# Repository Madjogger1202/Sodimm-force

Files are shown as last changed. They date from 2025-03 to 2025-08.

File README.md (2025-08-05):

# Sodimm-force rev0 
> [!IMPORTANT]
> Project wasn't produced and tested yet.
### Implementation of Orange Pi Zero 2W in sodimm form-factor
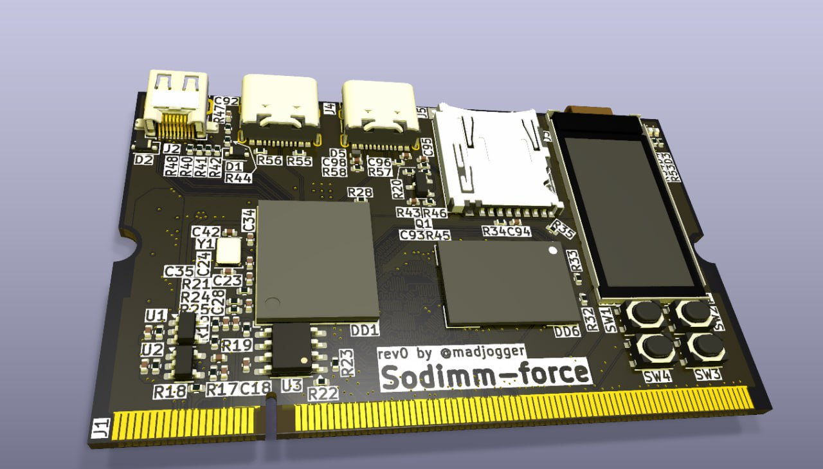
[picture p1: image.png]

<table style="width: 100%; table-layout: fixed;">
  <tr>
    <td rowspan="4">
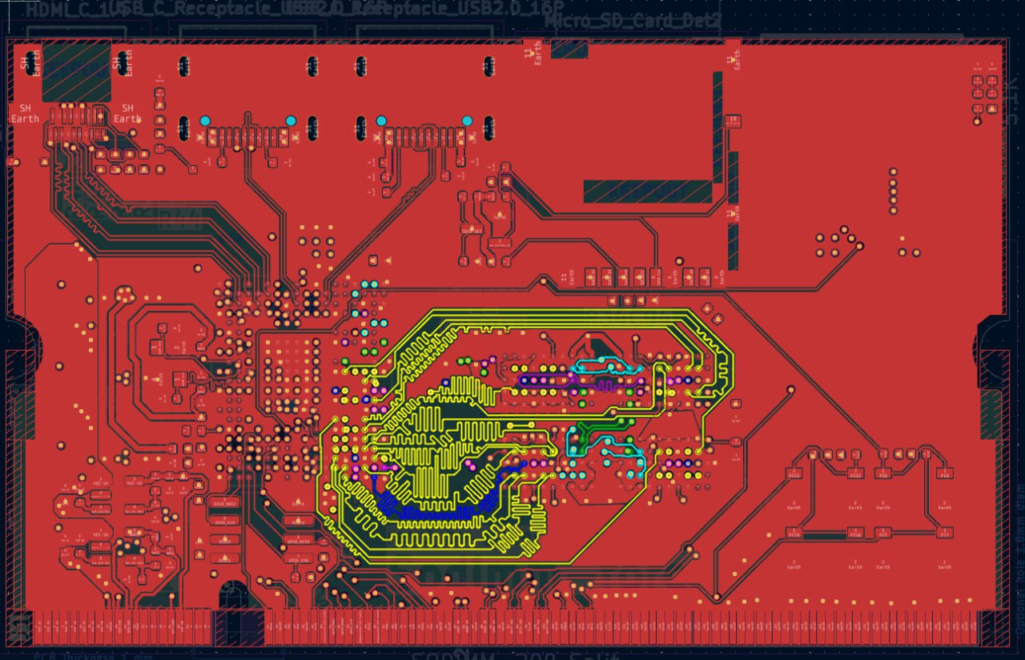
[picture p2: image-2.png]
      
    </td>  
    <td rowspan="4">
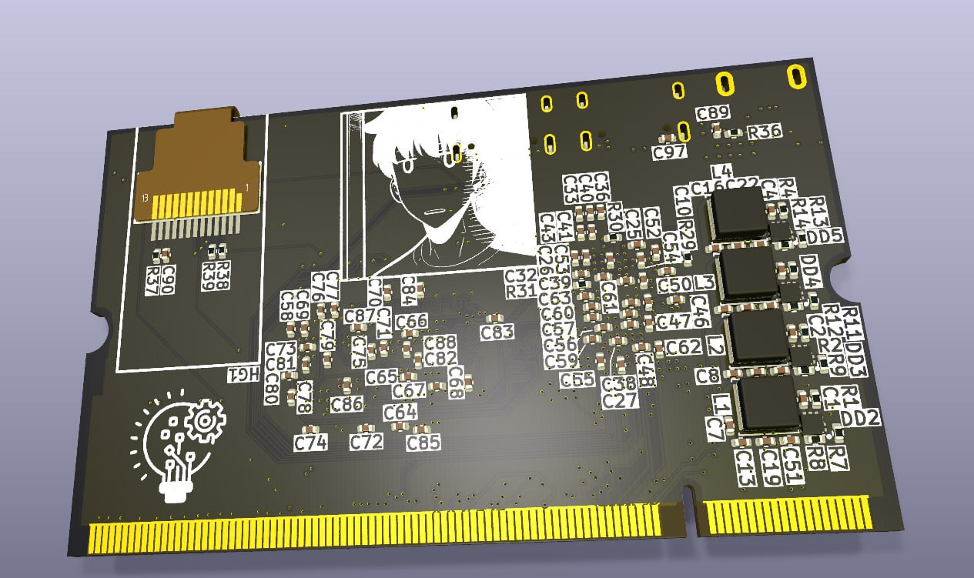
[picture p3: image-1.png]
      
    </td>  
  </tr>
</table>

## 🎲Revisions and logs:
<table>
  <tr>
    <td>
      <strong>Revision 0</strong>
    </td>   
    <td>
      <strong>10 March 2025</strong>
    </td> 
    <td>
      CPU H616, DDR MT53E1G32D2FW-046
    </td>
    <td>
      <strong>[x] not produced</strong>
    </td>
  </tr>
</table>

## 🧊 What Is This Project?

🐾 This entire project is just my take on an embedded compute module — but built around the Allwinner H616 SoC.

Not a clone. Not a dev board.  
Just **a compact, modular, SODIMM-sized brain** for custom systems. 💡

---

### 🛠️ The Vision

🐈 Made it to explore:
- How far can you push a **low-cost ARM SoC** in real embedded applications?
- Can we build something **industrial-grade**, yet **hackable and open**?
- What if your compute unit was **as easy to swap as RAM**?

So I said: *"Let’s make a tiny computer on a SODIMM."*  
And here we are. ✨

---

### 🔌 Key Features (SODIMM Form Factor)

- 🧩 **Modular by design** — plug into any carrier board
- 🧠 **Allwinner H616** — Quad-core Cortex-A53, Mali-G31 GPU, 4K@60 decoding
- 💾 **4GB LPDDR4** (Micron, automotive-grade) — fast & stable
- 💾 **microSD slot** — boot OS, store logs, update firmware
- 🖤 **EEPROM (ST M24M02)** — stores calibration, MAC, serials
- 📺 **0.96" IPS display (ST7735)** — built-in UI, no external screen needed
- 🔘 **4 tactile buttons** — navigate menus, trigger actions
- 🔌 **microHDMI 2.0** — 4K video out
- 🔌 **2× USB Type-C** — data, OTG, power
- ⚡ **DC-DC + LDO power** (SY8843QWC + SPX3819) — clean, efficient, stable
- 🛡️ **ESD protection** on all critical lines — because real world is harsh

---

### 🎯 Why H616?

🌟 Not the most powerful.  
🌟 Not the newest.  

But:
- ✅ **Mature Linux support** (Armbian, Debian, Buildroot)
- ✅ **Low power & heat** — perfect for fanless, compact designs
- ✅ **Full HDMI 2.0 + USB OTG** — rare at this price
- ✅ **Industrial temp RAM** — works where others fail
- ✅ **Open-ish ecosystem** — community-driven, no NDA hell

---

### 🧪 This Is a Prototype — Not Production

- 🚧 **Revision 0** — proof of concept
- ❌ `[x] not produced` — still not produced

## **˙✧˖°📷 ༘ ⋆｡˚ Stay tuned for further updates.˙✧˖°📷 ༘ ⋆｡˚**

### ***For any questions or collaborations i can be found on Telegram: [@madjogger](https://t.me/madjogger)***

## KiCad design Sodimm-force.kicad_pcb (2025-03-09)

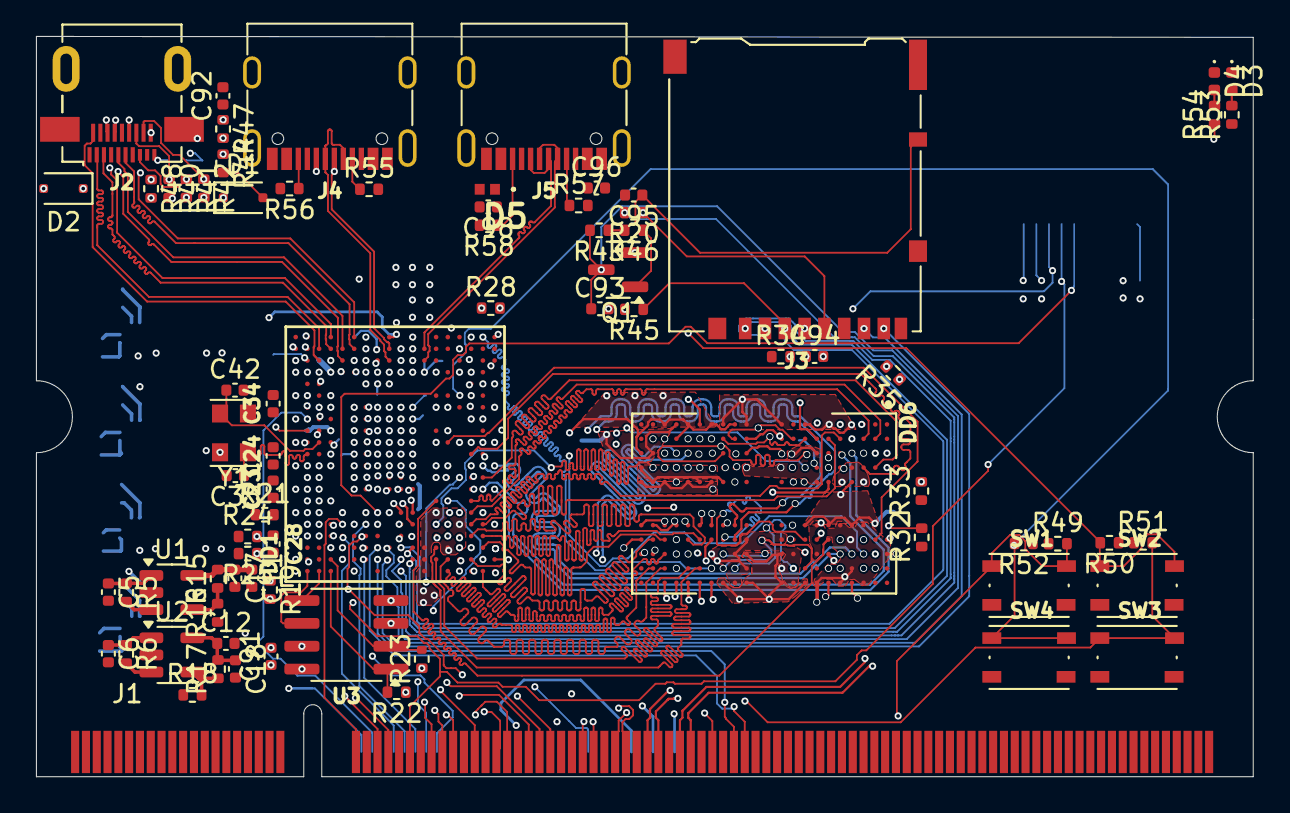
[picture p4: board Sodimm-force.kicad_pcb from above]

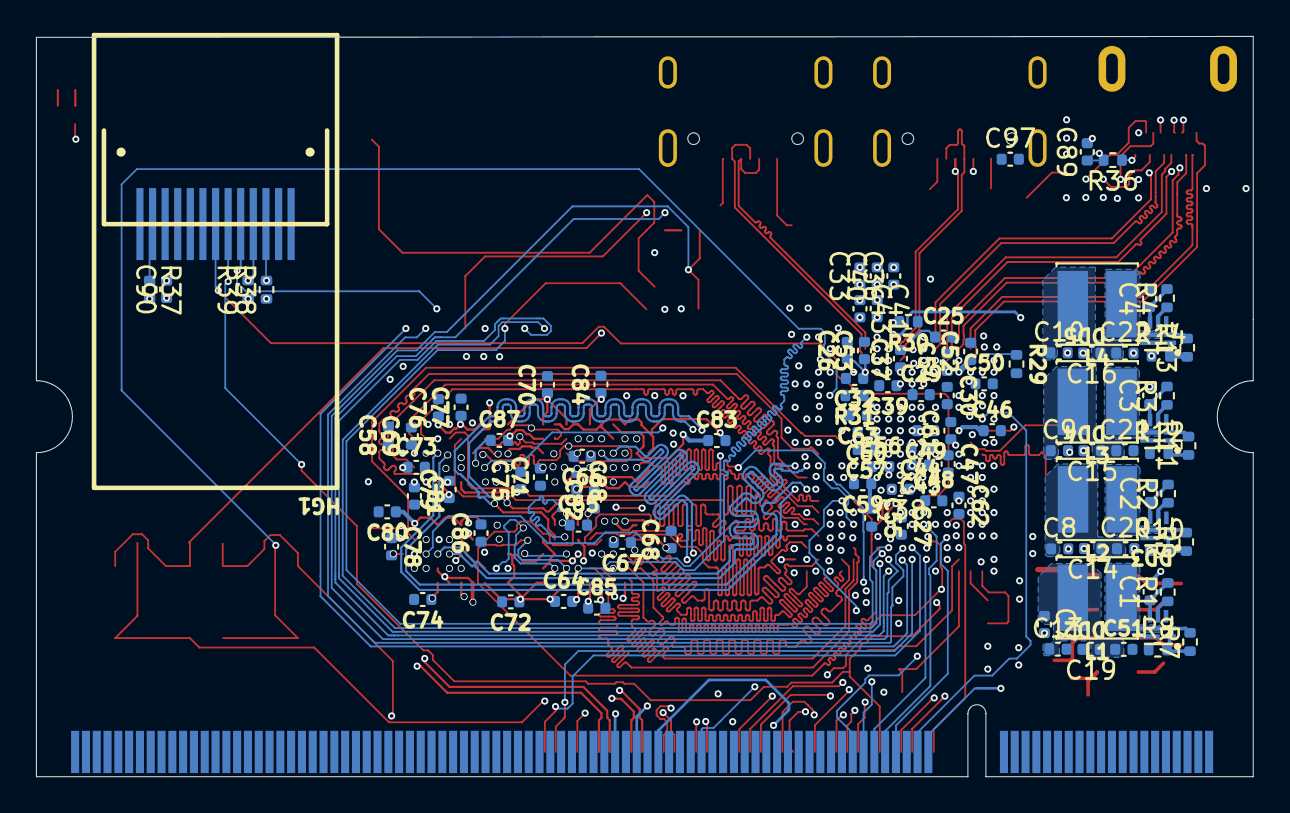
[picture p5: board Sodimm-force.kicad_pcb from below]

Board: 8 copper layers, 67.6 x 41.1 mm, 183 parts (106 on the bottom side), 182 nets.

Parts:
C1, C2, C3, C4, C5, C6, C7, C8, C9, C10, C11, C12, C19, C20, C21, C22, C33, C38, C41, C44, C47, C49, C53, C55, C64, C84, C90: 22uF; C_0402_1005Metric
C13, C14, C15, C16, C17, C18, C23, C24, C26, C28, C32, C61, C70, C71, C72, C73, C77, C78, C79, C80, C86, C88, C89, C92, C93, C95, C98: 100nF; C_0402_1005Metric
C25, C29, C52, C94, C96, C97: 10uF; C_0402_1005Metric
C27, C30, C34, C36, C40, C43, C45, C48, C51, C54, C56, C58, C60, C62, C65, C66, C67: 2.2uF; C_0402_1005Metric
C35, C42: 12p; C_0402_1005Metric
C37, C39, C46: 220nF; C_0402_1005Metric
C50, C57, C59, C63, C68, C69, C74, C75, C76, C81, C82, C83, C85, C87, C91: 1uF; C_0402_1005Metric
D1, D2: B5819WS; D_SOD-323F
D3, D4: LED-R; LED_0402_1005Metric
D5: AZ5825-01F; AZ582501F
DD1: H616
DD2, DD3, DD4, DD5: SY8843QWC
DD6: MT53E1G32D2FW-046_AUT_B; BGA200C65X80P22X12_1500X1000X114N
HG1: ST7735 0.96
J1: SODIMM-200_Split; SODIMM-200_2.5V_Card_edge
J2: HDMI_C_1.4; HDMI_Micro-D_Molex_46765-2x0x
J3: Micro_SD_Card_Det2; microSD_HC_Hirose_DM3AT-SF-PEJM5
J4, J5: USB_C_Receptacle_USB2.0_16P; USB_C_Receptacle_G-Switch_GT-USB-7010ASV
L1, L2, L3, L4: 0.68uH; L_Cenker_CKCS4020
Q1: 2N7002; SOT-23
R1, R2, R3, R4, R8, R10, R12, R22, R23, R24, R25, R38, R39, R49, R50, R51, R52: 10K; R_0402_1005Metric
R5, R6, R19: 0R; R_0402_1005Metric
R7: 5.1К; R_0402_1005Metric
R9: 6.8К; R_0402_1005Metric
R11: 8.32К; R_0402_1005Metric
R13: 41К; R_0402_1005Metric
R14: 9.1K; R_0402_1005Metric
R15: 16.9К; R_0402_1005Metric
R16: 10К; R_0402_1005Metric
R17: 4.7К; R_0402_1005Metric
R18: 10.2К; R_0402_1005Metric
R20, R21: 10R; R_0402_1005Metric
R28: 150K; R_0402_1005Metric
R29: 6K04; R_0402_1005Metric
R30, R31: 20K; R_0402_1005Metric
R32, R33: 240R; R_0402_1005Metric
R34, R35, R43, R45, R46: 100K; R_0402_1005Metric
R36: 1K; R_0402_1005Metric
R37, R40, R41, R42: 100R; R_0402_1005Metric
R44, R47, R48: 1.8K; R_0402_1005Metric
R53, R54, R57, R58: 5.1K; R_0402_1005Metric
R55, R56: 36K; R_0402_1005Metric
SW1, SW2, SW3, SW4: SW_Push; SW_Push_1P1T_NO_Vertical_Wuerth_434133025816
U1, U2: SPX3819M5-L; SOT-23-5
U3: SPI-EEPROM; SOIC-8_3.9x4.9mm_P1.27mm
Y1: X322524MKB4SI; Oscillator_SMD_EuroQuartz_XO32-4Pin_3.2x2.5mm

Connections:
AC-AVCC: C52.1, DD1.D18 (AC_AVCC)
AC-VRA1: C50.1, DD1.C17 (AC_VRA1)
AVCC: C12.1, C18.1, C23.1, C24.1, C25.1, C29.1, C34.1, C61.1, C62.1, C63.1, C84.1, C85.1, C86.1, C87.1, C88.1, DD1.D7 (VCC_PG), DD1.D11 (VCC_DCXO), DD1.D12 (VCC_PLL), DD1.F18 (VCC_HDMI), DD1.H17 (AVCC), DD1.H20 (VCC_TV), DD1.L14 (VDD18_DRAM), DD6.F12 (VDD1__1), DD6.G4 (VDD1__2), DD6.G9 (VDD1__3), DD6.T4 (VDD1__4), DD6.T9 (VDD1__5), DD6.U1 (VDD1__6), DD6.U12 (VDD1__7), J1.23, R17.2, R30.1, U2.5 (OUT)
DCDCE: C10.1, C16.1, C22.1, C90.1, C91.1, C94.1, DD5.2 (OUT), HG1.10 (VCC), J1.17, J3.4 (VDD), L4.2, R13.2, R22.1, R23.1, R24.1, R37.2, R38.1, R39.1, R43.1, R45.2, R46.2, R49.1, R50.1, R51.1, R52.1, R53.1, U3.3 (~W), U3.7 (~HOLD), U3.8 (VCC)
DCXO-XIN: C35.1, DD1.B11 (DXIN), Y1.1
DCXO-XOUT: C42.1, DD1.C12 (DXOUT), Y1.3
DXLDO-OUT: C46.1, DD1.D13 (DXLDO_OUT)
EPHY-RTX: DD1.B19 (EPHY_RTX), R29.1
EPHY-RXN: DD1.B21 (EPHY_RXN), J1.95
EPHY-RXP: DD1.B20 (EPHY_RXP), J1.97
EPHY-TXN: DD1.A20 (EPHY_TXN), J1.101
EPHY-TXP: DD1.A19 (EPHY_TXP), J1.103
Earth: C1.2, C2.2, C3.2, C4.2, C5.2, C6.2, C7.2, C8.2, C9.2, C10.2, C11.2, C12.2, C13.2, C14.2, C15.2, C16.2, C17.2, C18.2, C19.2, C20.2, C21.2, C22.2, C23.2, C24.2, C25.2, C26.2, C27.2, C28.2, C29.2, C30.2, C32.2, C33.2, C34.2, C35.2, C36.2, C37.2, C38.2, C39.2, C40.2, C41.2, C42.2, C43.2, C44.2, C45.2, C46.2, C47.2, C48.2, C49.2, C50.2, C51.2, C52.2, C53.2, C54.2, C55.2, C56.2, C57.2, C58.2, C59.2, C60.2, C61.2, C62.2, C63.2, C64.2, C65.2, C66.2, C67.2, C68.2, C69.2, C70.2, C71.2, C72.2, C73.2, C74.2, C75.2, C76.2, C77.2, C78.2, C79.2, C80.2, C81.2, C82.2, C83.2, C84.2, C85.2, C86.2, C87.2, C88.2, C89.2, C90.2, C91.2, C92.2, C93.2, C94.2, C95.2, C96.2, C97.2, C98.2, D3.1 (K), D4.1 (K), D5.2, DD1.A1 (GND_1), DD1.A10 (GND_2), DD1.A18 (GND_3), DD1.A21 (GND_4), DD1.B6 (GND_5), DD1.B16 (GND_6), DD1.D19 (GND_7), DD1.F14 (GND_8), DD1.F15 (GND_9), DD1.G13 (GND_10), DD1.G14 (GND_11), DD1.G15 (GND_12), DD1.H10 (GND_13), DD1.H11 (GND_14), DD1.H12 (GND_15), DD1.H13 (GND_16), DD1.H14 (GND_17), DD1.H15 (GND_18), DD1.H19 (GND_19), DD1.J12 (GND_20), DD1.J13 (GND_21), DD1.J14 (GND_22), DD1.J15 (GND_23), DD1.K8 (GND_24), DD1.K9 (GND_25), DD1.K10 (GND_26), DD1.K11 (GND_27), DD1.K12 (GND_28), DD1.K13 (GND_29), DD1.K14 (GND_30), DD1.K15 (GND_31), DD1.L21 (GND_32), DD1.M1 (GND_33), DD1.M2 (GND_34), DD1.M3 (GND_35), DD1.N6 (GND_36), DD1.N9 (GND_37), DD1.N12 (GND_38), DD1.N15 (GND_39), DD1.N18 (GND_40), DD1.P3 (GND_41), DD1.R5 (GND_42), DD1.R21 (GND_43), DD1.T1 (GND_44), DD1.T3 (GND_45), DD1.T8 (GND_46), DD1.T10 (GND_47), DD1.T15 (GND_48), DD1.T17 (GND_49), DD1.U6 (GND_50), DD1.U13 (GND_51), DD1.V1 (GND_52), DD1.V5 (GND_53), DD1.V12 (GND_54), DD1.V19 (GND_55), DD1.V21 (GND_56), DD2.7 (GND), DD3.7 (GND), DD4.7 (GND), DD5.7 (GND), DD6.A3 (VSS_1), DD6.A10 (VSS_1__1), DD6.AB3 (VSS_4), DD6.AB5 (VSS_4__1), DD6.AB8 (VSS_4__2), DD6.AB10 (VSS_4__3), DD6.C1 (VSS_1__2), DD6.C5 (VSS_1__3), DD6.C8 (VSS_1__4), DD6.C12 (VSS_1__5), DD6.D2 (VSS_1__6), DD6.D4 (VSS_1__7), DD6.D9 (VSS_1__8), DD6.D11 (VSS_1__9), DD6.E1 (VSS_1__10), DD6.E5 (VSS_1__11), DD6.E8 (VSS_1__12), DD6.E12 (VSS_1__13), DD6.G1 (VSS_1__14), DD6.G3 (VSS_2), DD6.G5 (VSS_2__1), DD6.G8 (VSS_2__2), DD6.G10 (VSS_2__3), DD6.G12 (VSS_2__4), DD6.J1 (VSS_2__5), DD6.J3 (VSS_2__6), DD6.J10 (VSS_2__7), DD6.J12 (VSS_2__8), DD6.K2 (VSS_2__9), DD6.K4 (VSS_2__10), DD6.K9 (VSS_2__11), DD6.K11 (VSS_2__12), DD6.N2 (VSS_2__13), DD6.N4 (VSS_3), DD6.N9 (VSS_3__1), DD6.N11 (VSS_3__2), DD6.P1 (VSS_3__3), DD6.P3 (VSS_3__4), DD6.P10 (VSS_3__5), DD6.P12 (VSS_3__6), DD6.T1 (VSS_3__7), DD6.T3 (VSS_3__8), DD6.T5 (VSS_3__9), DD6.T8 (VSS_3__10), DD6.T10 (VSS_3__11), DD6.T12 (VSS_3__12), DD6.V1 (VSS_3__13), DD6.V5 (VSS_3__14), DD6.V8 (VSS_4__4), DD6.V12 (VSS_4__5), DD6.W2 (VSS_4__6), DD6.W4 (VSS_4__7), DD6.W9 (VSS_4__8), DD6.W11 (VSS_4__9), DD6.Y1 (VSS_4__10), DD6.Y5 (VSS_4__11), DD6.Y8 (VSS_4__12), DD6.Y12 (VSS_4__13), HG1.8 (GND), HG1.11 (LEDK), HG1.13 (GND), J1.2, J1.4, J1.6, J1.8, J1.10, J1.12, J1.14, J1.16, J1.18, J1.20, J1.22, J1.24, J1.26, J1.28, J1.30, J1.32, J1.34, J1.36, J1.38, J1.40, J1.43, J1.46, J1.49, J1.53, J1.58, J1.60, J1.61, J1.62, J1.64, J1.65, J1.66, J1.68, J1.70, J1.71, J1.72, J1.74, J1.76, J1.78, J1.79, J1.80, J1.81, J1.82, J1.86, J1.87, J1.90, J1.93, J1.94, J1.98, J1.99, J1.102, J1.104, J1.105, J1.106, J1.108, J1.109, J1.110, J1.112, J1.114, J1.115, J1.116, J1.117, J1.118, J1.119, J1.120, J1.121, J1.122, J1.123, J1.124, J1.125, J1.126, J1.127, J1.128, J1.129, J1.130, J1.131, J1.132, J1.133, J1.134, J1.135, J1.136, J1.137, J1.138, J1.139, J1.140, J1.141, J1.142, J1.143, J1.144, J1.145, J1.146, J1.147, J1.148, J1.149, J1.150, J1.151, J1.152, J1.153, J1.154, J1.155, J1.156, J1.157, J1.158, J1.159, J1.160, J1.161, J1.162, J1.163, J1.164, J1.165, J1.166, J1.167, J1.168, J1.169, J1.170, J1.171, J1.172, J1.173, J1.174, J1.175, J1.176, J1.177, J1.178, J1.179, J1.180, J1.181, J1.182, J1.183, J1.184, J1.185, J1.186, J1.187, J1.188, J1.189, J1.190, J1.191, J1.192, J1.193, J1.194, J1.195, J1.196, J1.197, J1.198, J1.199, J1.200, J2.1 (D2S), J2.4 (D1S), J2.7 (D0S), J2.10 (CKS), J2.13 (GND), J2.SH, J3.6 (VSS), J3.9 (DET_B), J3.11 (SHIELD), J4.A1 (GND), J4.A12 (GND), J4.B1 (GND), J4.B12 (GND), J4.S1 (SHIELD), J5.A1 (GND), J5.A12 (GND), J5.B1 (GND), J5.B12 (GND), J5.S1 (SHIELD), Q1.2 (S), R8.1, R10.1, R12.1, R14.1, R16.1, R18.1, R25.2, R28.2, R29.2, R31.2, R32.1, R33.1, R55.2, R56.2, R57.2, R58.2, SW1.2, SW2.2, SW3.2, SW4.2, U3.4 (VSS), Y1.2, Y1.4
HCEC: DD1.G17 (HCEC), R40.2
HDMI0_TX_CEC_PORT: D1.1 (K), J2.14 (CEC), R40.1
HDMI0_TX_SCL_PORT: J2.15 (SCL), R41.1, R47.2
HDMI0_TX_SDA_PORT: J2.16 (SDA), R42.1, R48.2
HDMI-5V: C92.1, D2.1 (K), J2.18 (+5V), R47.1, R48.1
HHPD: C89.1, DD1.G18 (HHPD), R36.2
HSCL: DD1.F19 (HSCL), R41.2
HSDA: DD1.G21 (HSDA), R42.2
HTX0N: DD1.E20 (HTX0N), J2.9 (D0-)
HTX0P: DD1.E19 (HTX0P), J2.8 (D0+)
HTX1N: DD1.D21 (HTX1N), J2.6 (D1-)
HTX1P: DD1.D20 (HTX1P), J2.5 (D1+)
HTX2N: DD1.C20 (HTX2N), J2.3 (D2-)
HTX2P: DD1.C19 (HTX2P), J2.2 (D2+)
HTXCN: DD1.F21 (HTXCN), J2.12 (CK-)
HTXCP: DD1.F20 (HTXCP), J2.11 (CK+)
LINEOUTL: DD1.G19 (LINEOUTL), J1.100
LINEOUTR: DD1.G20 (LINEOUTR), J1.96
LRADC: DD1.L18 (LRADC), J1.107, R30.2
unnamed: D1.2 (A), R44.2
unnamed: D3.2 (A), R53.2
unnamed: D4.2 (A), R54.2
unnamed: DD1.K1 (PF2), R20.2
unnamed: DD1.A6 (PG0), R21.2
unnamed: DD1.L15 (SZQ), R31.1
unnamed: DD2.4 (EN), R1.1
unnamed: DD2.1 (FB), R7.1, R8.2
unnamed: DD2.6 (LX), L1.1
unnamed: DD3.4 (EN), R2.1
unnamed: DD3.1 (FB), R9.1, R10.2
unnamed: DD3.6 (LX), L2.1
unnamed: DD4.4 (EN), R3.1
unnamed: DD4.1 (FB), R11.1, R12.2
unnamed: DD4.6 (LX), L3.1
unnamed: DD5.4 (EN), R4.1
unnamed: DD5.1 (FB), R13.1, R14.2
unnamed: DD5.6 (LX), L4.1
unnamed: DD6.G2 (ODT_CA_A), R34.2
unnamed: DD6.T2 (ODT_CA_B), R35.2
unnamed: DD6.A5 (ZQ0), R33.2
unnamed: DD6.A8 (ZQ1), R32.2
unnamed: HG1.12 (LEDA), R37.1
unnamed: J2.19 (HPD/HEAC-), R36.1
unnamed: C95.1, J3.10 (DET_A), Q1.1 (G), R46.1
unnamed: J4.A5 (CC1), R55.1
unnamed: J4.B5 (CC2), R56.1
unnamed: J5.A5 (CC1), R57.1
unnamed: J5.B5 (CC2), R58.1
unnamed: R15.1, R16.2, U1.4 (ADJ)
unnamed: R5.2, U1.3 (EN)
unnamed: R17.1, R18.2, U2.4 (ADJ)
unnamed: R6.2, U2.3 (EN)
PC5: DD1.D3 (PC5), R25.1
PC6: DD1.E2 (PC6), R24.2
PC9: DD1.F1 (PC9), R19.2
PC12: DD1.G2 (PC12), J1.52
PC15: DD1.H2 (PC15), J1.111
PC16: DD1.H3 (PC16), J1.113
PH10/IR_RX: DD1.B13 (PH10), J1.84
PI0: DD1.H6 (PI0), HG1.7 (CS)
PI1: DD1.D4 (PI1), J1.73
PI3: DD1.E4 (PI3), J1.48
PI4: DD1.G5 (PI4), J1.50
PI6: DD1.H5 (PI6), J1.77
PI7: DD1.G4 (PI7), R51.2, SW3.1
PI8: DD1.E6 (PI8), R50.2, SW2.1
PI9: DD1.D5 (PI9), J1.56
PI10: DD1.L5 (PI10), R52.2, SW4.1
PI11: DD1.K4 (PI11), J1.54
PI12: DD1.K5 (PI12), J1.63, R49.2, SW1.1
PI13: DD1.E5 (PI13), J1.41
PI14: DD1.L6 (PI14), J1.75
PI15: DD1.L4 (PI15), HG1.6 (RES), J1.51
PI16: DD1.K6 (PI16), HG1.5 (RS)
REXT: DD1.K18 (REXT), R28.1
RX0: DD1.D15 (PH1), J1.69
RX5: DD1.C15 (PH3), J1.47
SA0: DD1.U17 (SA1), DD6.H2 (CA0_A), DD6.R2 (CA0_B)
SA1: DD1.V17 (SCS0), DD6.J2 (CA1_A), DD6.P2 (CA1_B)
SA2: DD1.T21 (SA0), DD6.H9 (CA2_A), DD6.R9 (CA2_B)
SA3: DD1.R20 (SCS1), DD6.H10 (CA3_A), DD6.R10 (CA3_B)
SA4: DD1.R18 (SA4), DD6.H11 (CA4_A), DD6.R11 (CA4_B)
SA5: DD1.T16 (SA3), DD6.J11 (CA5_A), DD6.P11 (CA5_B)
SCKE0: DD1.V15 (SCKE0), DD6.J4 (CKE0_A), DD6.P4 (CKE0_B)
SCKE1: DD1.P13 (SCKE1), DD6.J5 (SCKE1), DD6.P5 (SCKE1)
SCKN: DD1.U14 (SCKN), DD6.J9 (CK_C_A), DD6.P9 (CK_C_B)
SCKP: DD1.T14 (SCKP), DD6.J8 (CK_T_A), DD6.P8 (CK_T_B)
SCS0: DD1.T18 (SA2), DD6.H4 (CS0_A), DD6.R4 (CS0_B)
SCS1: DD1.P15 (SA5), DD6.H3 (CS1_A), DD6.R3 (CS1_B)
SDC0-CLK: J3.5 (CLK), R20.1
SDC0-CMD: DD1.K3 (PF3), J3.3 (CMD), R45.1
SDC0-D0: DD1.J3 (PF1), J3.7 (DAT0)
SDC0-D1: DD1.J2 (PF0), J3.8 (DAT1)
SDC0-D2: DD1.L3 (PF5), J3.1 (DAT2)
SDC0-D3: DD1.L2 (PF4), J3.2 (DAT3/CD)
SDC0-DET: C93.1, DD1.K2 (PF6), Q1.3 (D), R43.2
SDQ0: DD1.N3 (SDQ0), DD6.U11 (DQ11_B)
SDQ1: DD1.U4 (SDQ1), DD6.U9 (DQ12_B)
SDQ2: DD1.N2 (SDQ2), DD6.V11 (DQ10_B)
SDQ3: DD1.T4 (SDQ3), DD6.V9 (DQ13_B)
SDQ4: DD1.U3 (SDQ4), DD6.Y9 (DQ14_B)
SDQ5: DD1.P1 (SDQ5), DD6.AA11 (DQ8_B)
SDQ6: DD1.T2 (SDQ6), DD6.AA9 (DQ15_B)
SDQ7: DD1.P2 (SDQ7), DD6.Y11 (DQ9_B)
SDQ8: DD1.P5 (SDQ8), DD6.Y4 (DQ6_B)
SDQ9: DD1.V3 (SDQ9), DD6.V2 (DQ2_B)
SDQ10: DD1.P4 (SDQ10), DD6.Y2 (DQ1_B)
SDQ11: DD1.R4 (SDQ11), DD6.V4 (DQ5_B)
SDQ12: DD1.R6 (SDQ12), DD6.U2 (DQ3_B)
SDQ13: DD1.N4 (SDQ13), DD6.AA2 (DQ0_B)
SDQ14: DD1.P6 (SDQ14), DD6.U4 (DQ4_B)
SDQ15: DD1.N5 (SDQ15), DD6.AA4 (DQ7_B)
SDQ16: DD1.T11 (SDQ16), DD6.C4 (DQ6_A)
SDQ17: DD1.U12 (SDQ17), DD6.F4 (DQ4_A)
SDQ18: DD1.T12 (SDQ18), DD6.E4 (DQ5_A)
SDQ19: DD1.U9 (SDQ19), DD6.B4 (DQ7_A)
SDQ20: DD1.T6 (SDQ20), DD6.C2 (DQ1_A)
SDQ21: DD1.U5 (SDQ21), DD6.F2 (DQ3_A)
SDQ22: DD1.T7 (SDQ22), DD6.B2 (DQ0_A)
SDQ23: DD1.T5 (SDQ23), DD6.E2 (DQ2_A)
SDQ24: DD1.R9 (SDQ24), DD6.C9 (DQ14_A)
SDQ25: DD1.P7 (SDQ25), DD6.E9 (DQ13_A)
SDQ26: DD1.N7 (SDQ26), DD6.F9 (DQ12_A)
SDQ27: DD1.P9 (SDQ27), DD6.B11 (DQ8_A)
SDQ28: DD1.P10 (SDQ28), DD6.C11 (DQ9_A)
SDQ29: DD1.U11 (SDQ29), DD6.F11 (DQ11_A)
SDQ30: DD1.P12 (SDQ30), DD6.B9 (DQ15_A)
SDQ31: DD1.R12 (SDQ31), DD6.E11 (DQ10_A)
SDQM0: DD1.U1 (SDQM0), DD6.Y10 (DMI1_B)
SDQM1: DD1.R3 (SDQM1), DD6.Y3 (DMI0_B)
SDQM2: DD1.T9 (SDQM2), DD6.C3 (DMI0_A)
SDQM3: DD1.N10 (SDQM3), DD6.C10 (DMI1_A)
SDQS0N: DD1.R1 (SDQS0N), DD6.V10 (DQS1_C_B)
SDQS0P: DD1.R2 (SDQS0P), DD6.W10 (DQS1_T_B)
SDQS1N: DD1.V2 (SDQS1N), DD6.V3 (DQS0_C_B)
SDQS1P: DD1.U2 (SDQS1P), DD6.W3 (DQS0_T_B)
SDQS2N: DD1.U8 (SDQS2N), DD6.E3 (DQS0_C_A)
SDQS2P: DD1.V8 (SDQS2P), DD6.D3 (DQS0_T_A)
SDQS3N: DD1.U10 (SDQS3N), DD6.E10 (DQS1_C_A)
SDQS3P: DD1.V10 (SDQS3P), DD6.D10 (DQS1_T_A)
SPI0_CLK: DD1.B1 (PC0), U3.6 (C)
SPI0_CS0: DD1.D1 (PC3), R22.2, U3.1 (~S)
SPI0_MISO: DD1.D2 (PC4), R23.2, U3.2 (Q)
SPI0_MOSI: DD1.C1 (PC2), U3.5 (D)
SPI1_CLK: DD1.C14 (PH6), HG1.4 (SCL), J1.59, R39.2
SPI1_CS0: DD1.B14 (PH5), J1.44
SPI1_CS1: DD1.A12 (PH9), J1.42
SPI1_MISO: DD1.C13 (PH8), J1.57
SPI1_MOSI: DD1.B12 (PH7), HG1.3 (SDA), J1.55, R38.2
SRST: DD1.U21 (SRST), DD6.T11 (~RESET)
STATUS-LED: DD1.G3 (PC13), R54.1
TV-OUT: DD1.J21 (TV_OUT), J1.92
TX0: DD1.D16 (PH0), J1.67
TX5: DD1.B15 (PH2), J1.45
USB0-DN: DD1.J19 (USB0_DM), J4.A7 (D-), J4.B7 (D-)
USB0-DP: DD1.J20 (USB0_DP), J4.A6 (D+), J4.B6 (D+)
USB1-DN: DD1.M19 (USB1_DM), J5.A7 (D-), J5.B7 (D-)
USB1-DP: DD1.M20 (USB1_DP), J5.A6 (D+), J5.B6 (D+)
USB2-DN: DD1.K19 (USB2_DM), J1.89
USB2-DP: DD1.K20 (USB2_DP), J1.91
USB3-DN: DD1.L19 (USB3_DM), J1.83
USB3-DP: DD1.L20 (USB3_DP), J1.85
VCC-5V: C1.1, C2.1, C3.1, C4.1, C5.1, C6.1, C96.1, C97.1, C98.1, D2.2 (A), D5.1, DD2.5 (IN), DD3.5 (IN), DD4.5 (IN), DD5.5 (IN), J1.1, J1.3, J1.5, J1.7, J1.9, J1.11, J1.13, J1.15, J4.A4 (VBUS), J4.A9 (VBUS), J4.B4 (VBUS), J4.B9 (VBUS), J5.A4 (VBUS), J5.A9 (VBUS), J5.B4 (VBUS), J5.B9 (VBUS), R1.2, R2.2, R3.2, R4.2, R5.1, R6.1, U1.1 (IN), U2.1 (IN)
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

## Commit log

2025-02-09 Initial commit Готова общая структура схемы, заполнены форматки и расставлена часть элементов по схеме
    [CPU.kicad_sch, DDR.kicad_sch, Display and interface.kicad_sch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]
2025-02-10 расставлены основные блоки и компоненты, подобраны компоненты интерфейса и питания
    [CPU.kicad_sch, DDR.kicad_sch, Display and interface.kicad_sch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]
2025-02-12 Внесены распиновки интерфейсного модуля и модуля GPIO + конденсаторы по питанию 2/7 референсной схемы
    [CPU.kicad_sch, Display and interface.kicad_sch]
2025-02-14 Доработка DDR, питание
    [DDR.kicad_sch, Sodimm-force.kicad_pcb, power.kicad_sch]
2025-02-14 Обновлена структура, закончен интерфейс, HDMI Завершено проектирование линий питания и подтяжек для интерфейсов
    [CPU.kicad_sch, Display and interface.kicad_sch, HDMI + usb.kicad_sch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]
2025-02-17 Схема закончена, часть компонентов расставлена на плате
    [CPU.kicad_sch, DDR.kicad_sch, HDMI + usb.kicad_sch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]
2025-02-17 Пытаюсь сделать трассировку DDК
    [CPU.kicad_sch, DDR.kicad_sch, Sodimm-force.kicad_pcb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]
2025-02-18 вроде хехе чуть трассировки DDR
    [Sodimm-force.kicad_pcb]
2025-02-19 пу-пу-пу
    [Sodimm-force.kicad_pcb]
2025-02-20 Добавлены предельные правила
    [Sodimm-force.kicad_pcb]
2025-02-24 Трассировка с полными соединениями DDR
    [Sodimm-force.kicad_pcb]
2025-02-28 Согласовал по длине 1.5 слоя
    [Sodimm-force.kicad_pcb]
2025-03-01 DDR оттрассирована!! 🥹
    [Sodimm-force.kicad_pcb]
2025-03-01 Кучка исправлений, переместил SD карту, дисплей, в целом компоновка чуть другая Небольшие исправления в схеме 🤠
    [CPU.kicad_sch, DDR.kicad_sch, HDMI + usb.kicad_sch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]
2025-03-01 Навёл красоту, убрал подтяжку для питания что скопировал с реф дизайна ( у меня не умные DC-DC ) + компоновка decoupling кондёров и быстрой обвязки чипа
    [CPU.kicad_sch, DDR.kicad_sch, Sodimm-force.kicad_pcb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]
2025-03-09 Проведены все линии данных, осталось лишь сделать полигонами питание и шелкографию исправить :)
    [CPU.kicad_sch, DDR.kicad_sch, HDMI + usb.kicad_sch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]
2025-03-10 Чаcтичная трассировка питания
2025-03-10 rev0 готова
    [CPU.kicad_sch, DDR.kicad_sch, Sodimm-force.kicad_sch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]
2025-03-11 Небольшое исправление шелкографии, дозалил остальные слои землёй для понижения общего импеданса
2025-03-11 Добавлен BOM
2025-05-20 Исправление УГО по ГОСТу, добавление 3D моделей
    [CPU.kicad_sch, DDR.kicad_sch, HDMI + usb.kicad_sch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]
2025-05-22 GOST update
    [CPU.kicad_sch, DDR.kicad_sch, HDMI + usb.kicad_sch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]
2025-08-05 рефакторинг структуры, проверка Readme
    [CPU.kicad_sch, DDR.kicad_sch, power.kicad_sch]
2025-08-05 upd readme
    [CPU.kicad_sch, DDR.kicad_sch, Display and interface.kicad_sch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]
